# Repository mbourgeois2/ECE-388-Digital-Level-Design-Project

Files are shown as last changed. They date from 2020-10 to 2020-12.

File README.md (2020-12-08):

# ECE-388-Digital-Level-Design-Project
This is my Embedded Systems Design Project for ECE-388, the digital level. The design works as follows. The accelerometer will measure the necessary data. The measured data will then be sent to the PINs of the 328PB and the board tilt angle will be calculated. Firmware written on the microcontroller will determine which LEDs in the LED array to light up based on the data given by the accelerometer. This information will then be output from the PORTs of the 328PB and light up the LEDs accordingly. The LEDs will light up in a similar manner to the movement of a bubble in a bubble level. When the board is completely level, the center LED will turn green. 

Demo video: https://youtu.be/xUTPTQpNgwE (could not fit the MP4 file in the repo, had to upload it to youtube)

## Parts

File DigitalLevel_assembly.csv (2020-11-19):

UUID | Qty | Self Sourced | Value | Device | Package | Parts | Description
R-2019-15 | 8 |  | R | LEDCHIP-LED0805 | CHIP-LED0805 | LED1, LED2, LED3, LED4, LED5, LED6, LED7, LED8 | LED
R-2019-14 | 1 |  | G | LEDCHIPLED_0805 | CHIPLED_0805 | LED9 | LED
R-2019-01 | 5 |  | 0.1uF | C-EUC0805 | C0805 | C1, C2, C3, C4, C7 | CAPACITOR, European symbol
R-2019-44 | 1 |  | 10nF | C-EUC0805 | C0805 | C5 | CAPACITOR, European symbol
R-2019-38 | 1 |  | 1nF | C-EUC0805 | C0805 | C6 | CAPACITOR, European symbol
R-2019-02 | 1 |  | 330R | R-EU_R0805 | R0805 | R1 | RESISTOR, European symbol
R-2019-30 | 3 |  | 4.7kR | R-EU_R0805 | R0805 | R2, R3, R4 | RESISTOR, European symbol
L-2020-48 | 1 |  | ATMEGA328PB-AU | ATMEGA328PB-AU | QFP80P900X900X120-32N | U1 | ATmega Series 20 MHz 32 KB Flash 2 KB SRAM 8-Bit Microcontroller - TQFP-32 Check prices
L-2020-54 | 1 |  | MPU-6050 | MPU-6050 | QFN50P400X400X95-24N | U2 | MPU-6050 Six-Axis (Gyro + Accelerometer) MEMS MotionTrackingâ„¢ Devices
L-2019-90 | 1 |  | RK-2032 | RK-2032 | RK-2032 | BAT1
R-2019-19 | 1 |  | SL2305 | SL2305 | SOT95P240X115-3N | Q1 | P-Channel Power MOSFET
L-2019-76 | 1 |  | SN74HC138PW | SN74HC138PW | SOP65P640X120-16N | U3

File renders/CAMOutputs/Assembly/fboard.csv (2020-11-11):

Qty | Value | Device | Package | Parts | Description | ARROW_PART_NUMBER | ARROW_PRICE-STOCK | AVAILABILITY | DESCRIPTION | DIGI-KEY_PART_NUMBER | HEIGHT | MANUFACTURER_NAME | MANUFACTURER_PART_NUMBER | MF | MOUSER_PART_NUMBER | MOUSER_PRICE-STOCK | MP | PACKAGE | POPULARITY | PRICE | PURCHASE-URL | SPICEPREFIX
8 |  | LEDCHIP-LED0805 | CHIP-LED0805 | LED1, LED2, LED3, LED4, LED5, LED6, LED7, LED8 | LED
1 |  | LEDCHIPLED_0805 | CHIPLED_0805 | LED9 | LED
5 | 0.1uF | C-EUC0805 | C0805 | C1, C2, C3, C4, C7 | CAPACITOR, European symbol |  |  |  |  |  |  |  |  |  |  |  |  |  | 88 |  |  | C
1 | 10nF | C-EUC0805 | C0805 | C5 | CAPACITOR, European symbol |  |  |  |  |  |  |  |  |  |  |  |  |  | 88 |  |  | C
1 | 2nF | C-EUC0805 | C0805 | C6 | CAPACITOR, European symbol |  |  |  |  |  |  |  |  |  |  |  |  |  | 88 |  |  | C
1 | 330R | R-EU_R0805 | R0805 | R1 | RESISTOR, European symbol |  |  |  |  |  |  |  |  |  |  |  |  |  | 86 |  |  | R
3 | 4.7kR | R-EU_R0805 | R0805 | R2, R3, R4 | RESISTOR, European symbol |  |  |  |  |  |  |  |  |  |  |  |  |  | 86 |  |  | R
1 | ATMEGA328PB-AU | ATMEGA328PB-AU | QFP80P900X900X120-32N | U1 | ATmega Series 20 MHz 32 KB Flash 2 KB SRAM 8-Bit Microcontroller - TQFP-32 Check prices |  |  | Good | 8-bit Microcontrollers - MCU ATMEGA328PB 20MHZ IND TEMP |  |  |  |  | Microchip Technology / Atmel |  |  | ATMEGA328PB-AU | None |  | None | https://pricing.snapeda.com/search/part/ATMEGA328PB-AU/?ref=eda
1 | AVRISP-6 | AVRISP-6 | AVRISP | ISP1 | AVR ISP HEADER
3 | FIDUCIAL | FIDUCIAL | FIDUCIAL_1MM | U$4, U$5, U$6 | For use by pick and place machines to calibrate the vision/machine, 1mm
1 | MPU-6050 | MPU-6050 | QFN50P400X400X95-24N | U2 | MPU-6050 Six-Axis (Gyro + Accelerometer) MEMS MotionTracking™ Devices |  |  |  | Accelerometer, Gyroscope, 6 Axis Sensor I²C Output | 1428-1007-1-ND |  |  |  | TDK InvenSense |  |  | MPU-6050 | VFQFN-24 TDK InvenSense |  |  | https://pricing.snapeda.com/search/part/MPU-6050/?ref=eda
1 | RK-2032 | RK-2032 | RK-2032 | BAT1
1 | SL2305 | SL2305 | SOT95P240X115-3N | Q1 | P-Channel Power MOSFET |  |  |  | P-Channel Power MOSFET |  | 1.15mm | Slkor(SLKORMICRO Elec.) | SL2305
1 | SN74HC138PW | SN74HC138PW | SOP65P640X120-16N | U3 |  |  |  | Unavailable | 3-Line To 8-Line Decoders/Demultiplexers 16-TSSOP -40 to 85 |  |  |  |  | Texas Instruments |  |  | SN74HC138PW | TSSOP-16 Texas Instruments |  | None | https://pricing.snapeda.com/search/part/SN74HC138PW/?ref=eda

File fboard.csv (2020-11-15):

Qty | Value | Device | Package | Tolerance | Rating | Parts | Description | LCSC Price 1 | LCSC Price 10 | LCSC Price 100 | LCSC PN | LCSC Link | Digikey Price 1 | Digikey Price 10 | Digikey Price 100 | Digikey PN | Digikey Link | Alt Supplier | Alt Supplier Link
8 | R | LEDCHIP-LED0805 | CHIP-LED0805 |  |  | LED1, LED2, LED3, LED4, LED5, LED6, LED7, LED8 | LED |  |  | $0.014157 | C72044 | https://lcsc.com/product-detail/Light-Emitting-Diodes-LED_0603-Red-LED_C72044.html
1 | G | LEDCHIPLED_0805 | CHIPLED_0805 |  |  | LED9 | LED |  | $0.062285 | $0.046420 | C73546 | https://lcsc.com/product-detail/Light-Emitting-Diodes-LED_0805-Green_C73546.html
5 | 0.1uF | C-EUC0805 | C0805 | 5% | 50V | C1, C2, C3, C4, C7 | CAPACITOR, European symbol |  |  | $0.008557 | C840115 | https://lcsc.com/product-detail/Multilayer-Ceramic-Capacitors-MLCC-SMD-SMT_HUI-JU-NL0805B104J500CPBN_C840115.html
1 | 10nF | C-EUC0805 | C0805 | 5% | 50V | C5 | CAPACITOR, European symbol |  |  | $0.010582 | C24666 | https://lcsc.com/product-detail/Multilayer-Ceramic-Capacitors-MLCC-SMD-SMT_FH-Guangdong-Fenghua-Advanced-Tech-0805B103J500NT_C24666.html
1 | 2nF | C-EUC0805 | C0805 | 5% | 50V | C6 | CAPACITOR, European symbol |  |  | $0.024456 | C520022 | https://lcsc.com/product-detail/Multilayer-Ceramic-Capacitors-MLCC-SMD-SMT_YAGEO-CC0805JRX7R9BB202_C520022.html
1 | 330R | R-EU_R0805 | R0805 | 5% | 0.125W | R1 | RESISTOR, European symbol |  |  | $0.001490 | C25306 | https://lcsc.com/product-detail/Chip-Resistor-Surface-Mount_UNI-ROYAL-Uniroyal-Elec-0805W8J0331T5E_C25306.html
3 | 4.7kR | R-EU_R0805 | R0805 | 5% | 0.125W | R2, R3, R4 | RESISTOR, European symbol |  |  | $0.001350 | C384092 | https://lcsc.com/product-detail/Chip-Resistor-Surface-Mount_Walsin-Tech-Corp-Walsin-Tech-Corp-4-7KR-472-5_C384092.html
1 | ATMEGA328PB-AU | ATMEGA328PB-AU | QFP80P900X900X120-32N |  |  | U1 | ATmega Series 20 MHz 32 KB Flash 2 KB SRAM 8-Bit Microcontroller - TQFP-32 Check prices |  |  |  |  |  | $1.45000 | $1.45000 | $1.20000 | ATMEGA328PB-ANRTR-ND - Tape & Reel (TR) | https://www.digikey.com/en/products/detail/microchip-technology/ATMEGA328PB-ANR/5722705
1 | AVRISP-6 | AVRISP-6 | AVRISP |  |  | ISP1 | AVR ISP HEADER |  |  |  |  |  | $0.16000 | $0.15100 | $0.10480 | S2212EC-03-ND | https://www.digikey.com/en/products/detail/sullins-connector-solutions/PREC003DFAN-RC/2775011
1 | CR2032V | CR2032V | CR2032V |  |  | G1 | LI BATTERY Varta |  |  |  |  |  |  |  |  |  |  | Aliexpress | https://www.aliexpress.com/item/4000204085959.html
1 | MPU-6050 | MPU-6050 | QFN50P400X400X95-24N |  |  | U2 | MPU-6050 Six-Axis (Gyro + Accelerometer) MEMS MotionTrackingâ„¢ Devices | $2.663333 | $1.961667 | $1.703333 | C24112 | https://lcsc.com/product-detail/Attitude-Sensors_TDK-InvenSense_MPU-6050_TDK-InvenSense-MPU-6050_C24112.html
1 | RK-2032 | RK-2032 | RK-2032 |  |  | BAT1 |  |  |  |  |  |  |  |  |  |  |  | Reekart | http://www.reekart.com/products/30-Surface-Mount-Precision-Metal-Stamping-CR2032-Coin-Cell-Battery-Holder-For-MPD-BC-2003-Replacment.html
1 | SL2305 | SL2305 | SOT95P240X115-3N |  |  | Q1 | P-Channel Power MOSFET |  |  | $0.028500 | C426573 | https://lcsc.com/product-detail/MOSFET_Slkor-SLKORMICRO-Elec-SL2305_C426573.html
1 | SN74HC138PW | SN74HC138PW | SOP65P640X120-16N |  |  | U3 |  | $0.148700 | $0.108800 | $0.094200 | C157527 | https://lcsc.com/product-detail/74-Series_Texas-Instruments_SN74HC138PWR_Texas-Instruments-Texas-Instruments-SN74HC138PWR_C157527.html

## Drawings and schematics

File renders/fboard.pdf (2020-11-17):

A

A

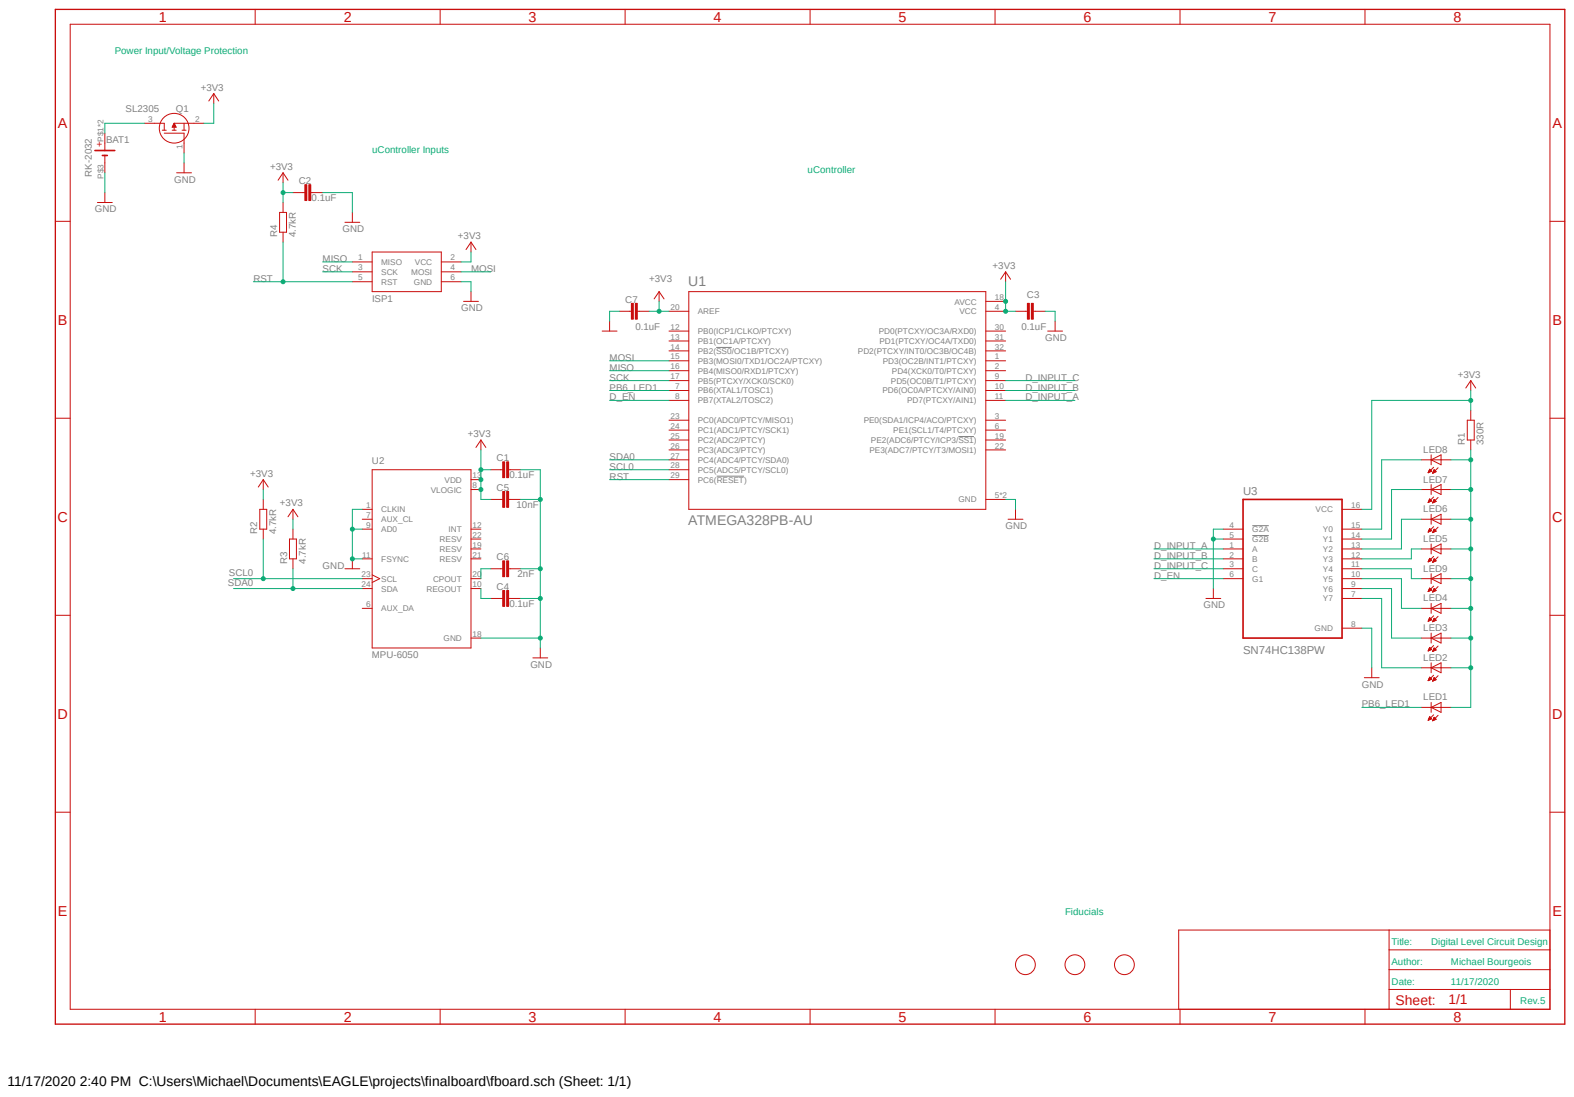
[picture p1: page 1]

Power Input/Voltage Protection

11/17/2020 2:40 PM C:\Users\Michael\Documents\EAGLE\projects\finalboard\fboard.sch (Sheet: 1/1)

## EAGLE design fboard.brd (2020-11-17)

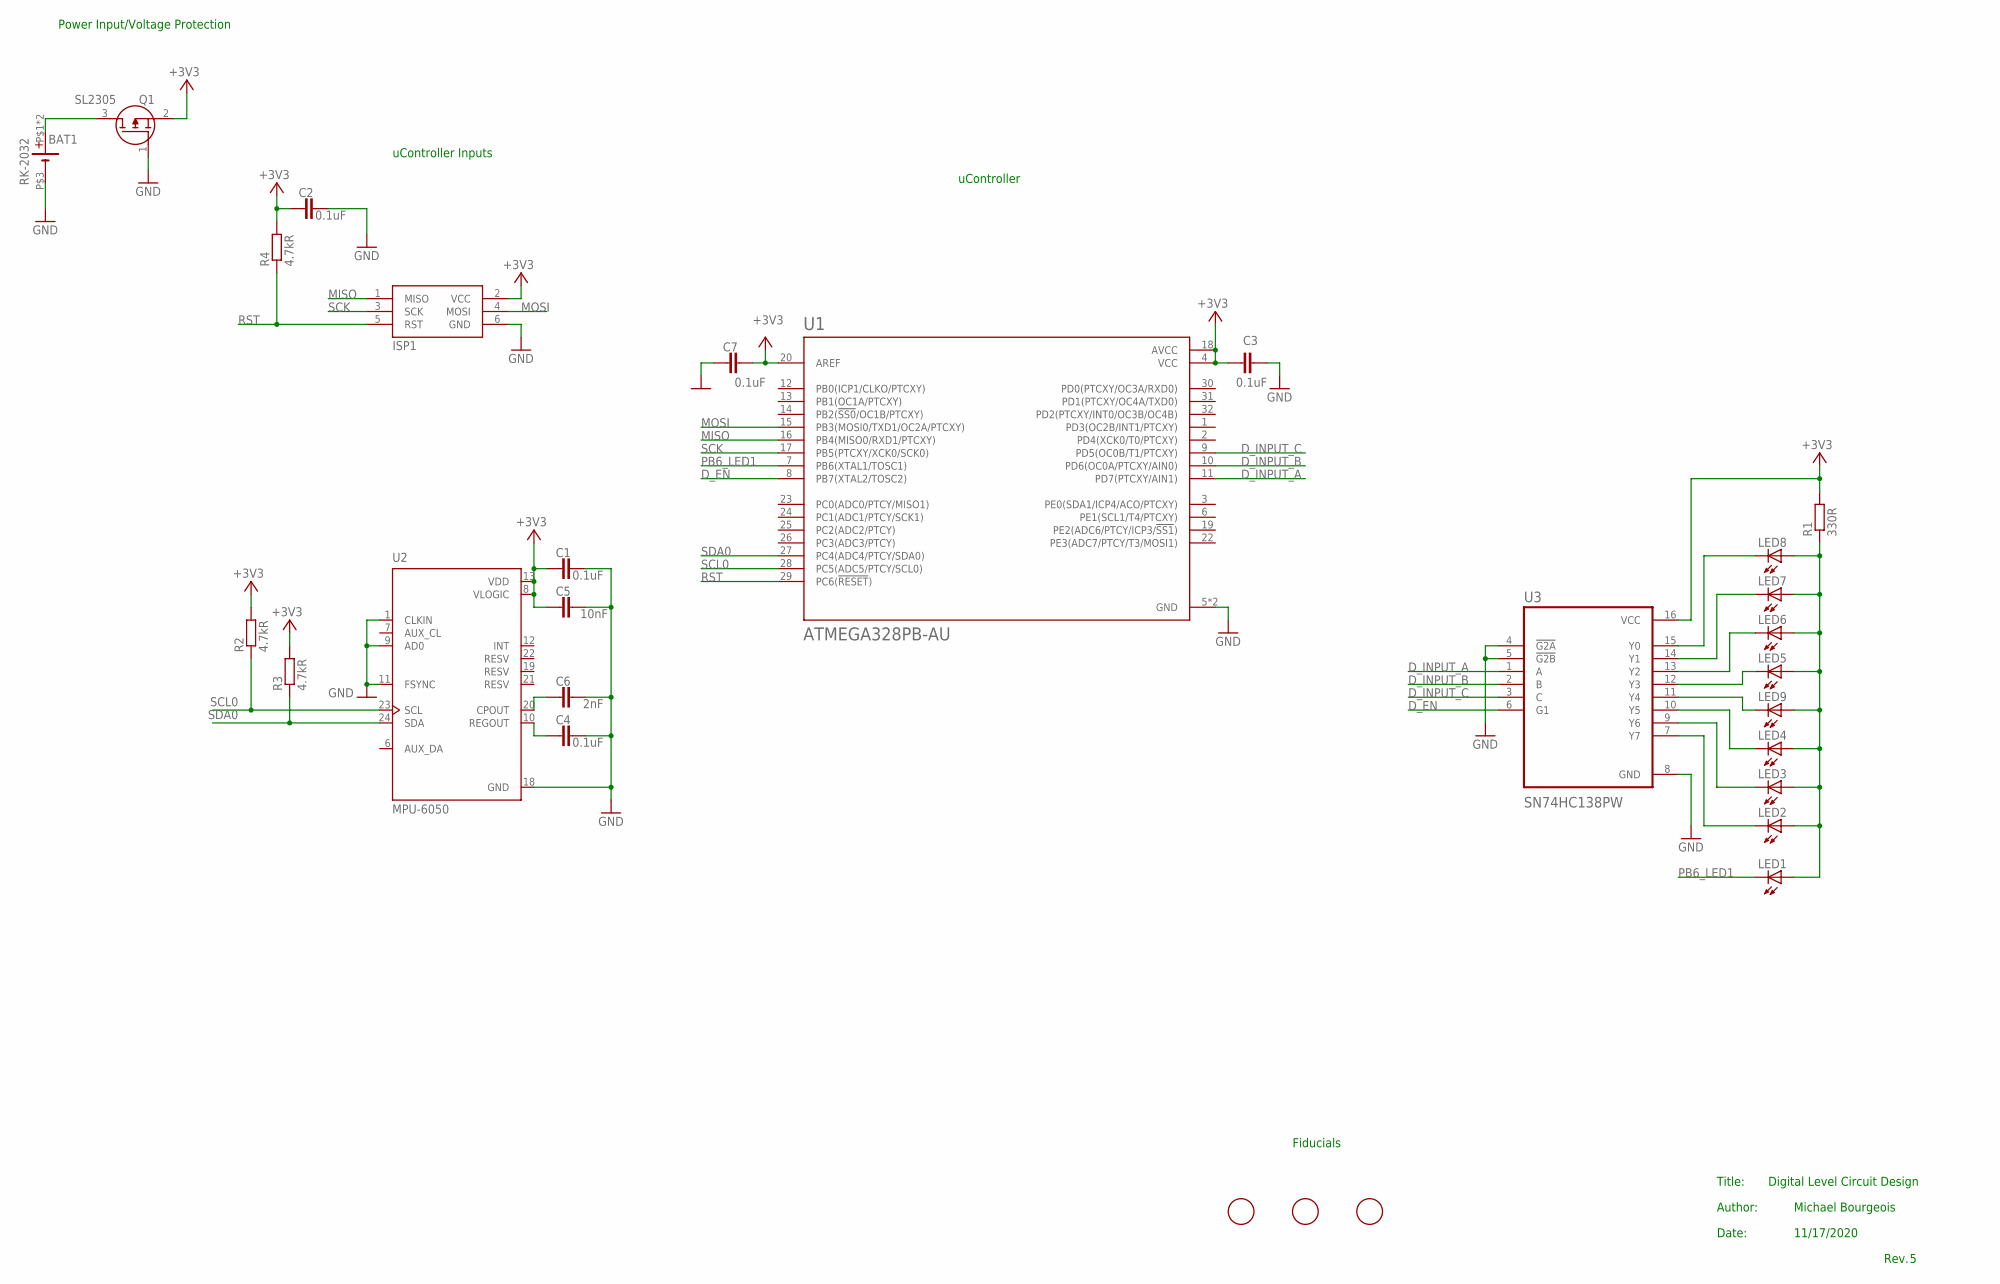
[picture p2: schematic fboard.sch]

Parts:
BAT1: RK-2032
C1, C2, C3, C4, C7: 0.1uF; C0805
C5: 10nF; C0805
C6: 2nF; C0805
ISP1: AVRISP-6; AVRISP
LED1, LED2, LED3, LED4, LED5, LED6, LED7, LED8: LEDCHIP-LED0805; CHIP-LED0805
LED9: LEDCHIPLED_0805; CHIPLED_0805
Q1: SL2305; SOT95P240X115-3N
R1: 330R; R0805
R2, R3, R4: 4.7kR; R0805
U1: ATMEGA328PB-AU; QFP80P900X900X120-32N
U2: MPU-6050; QFN50P400X400X95-24N
U3: SN74HC138PW; SOP65P640X120-16N
U$4, U$5, U$6: FIDUCIAL; FIDUCIAL_1MM

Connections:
+3V3: C1.1, C2.1, C3.1, C5.1, C7.1, ISP1.2 (VCC), Q1.2 (S), R1.2, R2.2, R3.2, R4.2, U1.4 (VCC), U1.18 (AVCC), U1.20 (AREF), U2.8 (VLOGIC), U2.13 (VDD), U3.16 (VCC)
D_EN: U1.8 (PB7(XTAL2/TOSC2)), U3.6 (G1)
D_INPUT_A: U1.11 (PD7(PTCXY/AIN1)), U3.1 (A)
D_INPUT_B: U1.10 (PD6(OC0A/PTCXY/AIN0)), U3.2 (B)
D_INPUT_C: U1.9 (PD5(OC0B/T1/PTCXY)), U3.3 (C)
GND: BAT1.P$3 (-), C1.2, C2.2, C3.2, C4.2, C5.2, C6.2, C7.2, ISP1.6 (GND), Q1.1 (G), U1.5 (GND), U1.21 (GND), U2.1 (CLKIN), U2.9 (AD0), U2.11 (FSYNC), U2.18 (GND), U3.4 (!G2A), U3.5 (!G2B), U3.8 (GND)
LED_LINE: LED1.A, LED2.A, LED3.A, LED4.A, LED5.A, LED6.A, LED7.A, LED8.A, LED9.A, R1.1
MISO: ISP1.1 (MISO), U1.16 (PB4(MISO0/RXD1/PTCXY))
MOSI: ISP1.4 (MOSI), U1.15 (PB3(MOSI0/TXD1/OC2A/PTCXY))
unnamed: C4.1, U2.10 (REGOUT)
unnamed: C6.1, U2.20 (CPOUT)
unnamed: BAT1.P$1 (+), BAT1.P$2 (+), Q1.3 (D)
PB6_LED1: LED1.C, U1.7 (PB6(XTAL1/TOSC1))
RST: ISP1.5 (RST), R4.1, U1.29 (PC6(!RESET!))
SCK: ISP1.3 (SCK), U1.17 (PB5(PTCXY/XCK0/SCK0))
SCL0: R2.1, U1.28 (PC5(ADC5/PTCY/SCL0)), U2.23 (SCL)
SDA0: R3.1, U1.27 (PC4(ADC4/PTCY/SDA0)), U2.24 (SDA)
Y0: LED8.C, U3.15 (Y0)
Y1: LED7.C, U3.14 (Y1)
Y2: LED6.C, U3.13 (Y2)
Y3: LED5.C, U3.12 (Y3)
Y4: LED9.C, U3.11 (Y4)
Y5: LED4.C, U3.10 (Y5)
Y6: LED3.C, U3.9 (Y6)
Y7: LED2.C, U3.7 (Y7)

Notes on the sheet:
11/17/2020
Michael Bourgeois
Title:
Digital Level Circuit Design
Author:
Date:
Rev.
Power Input/Voltage Protection
uController Inputs
uController
Fiducials

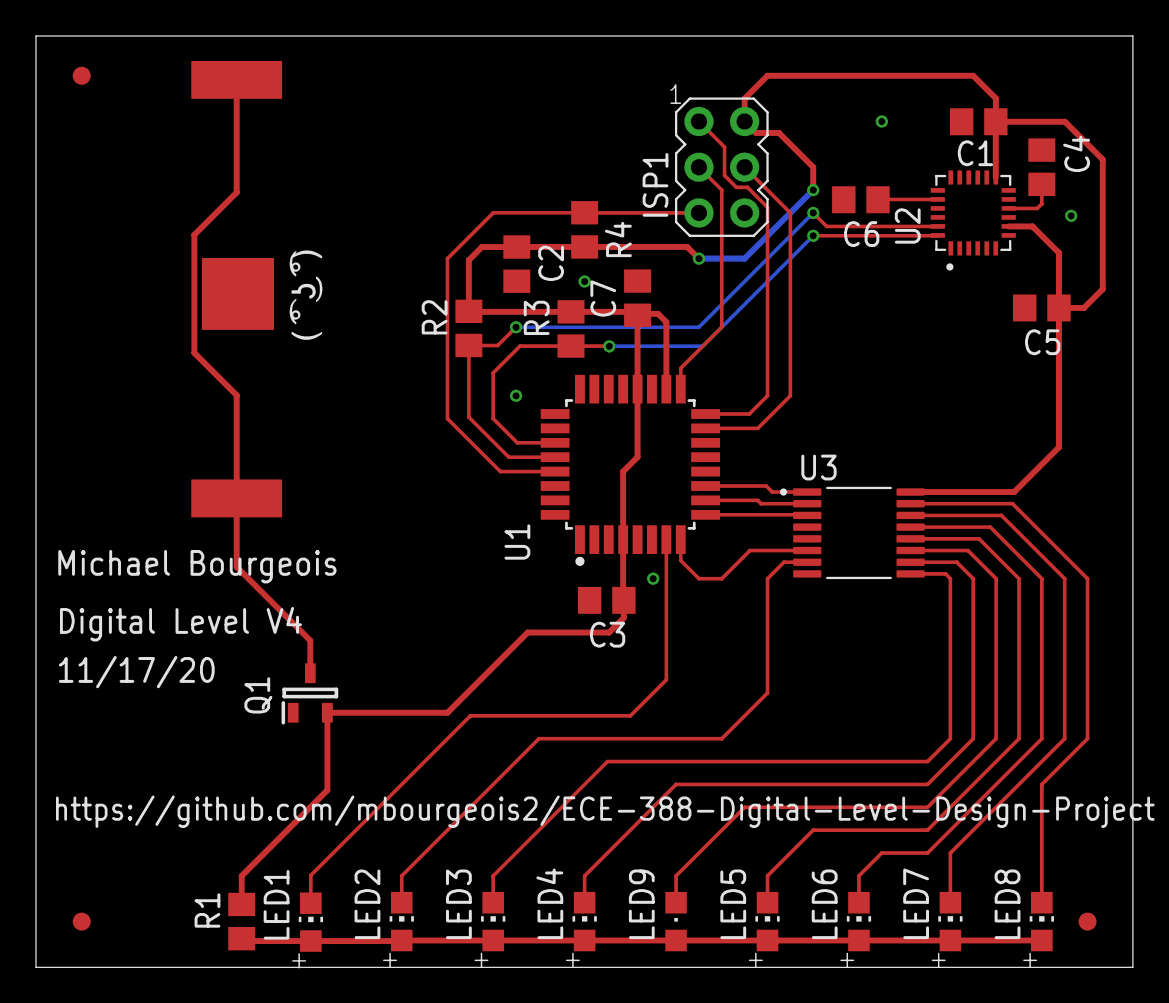
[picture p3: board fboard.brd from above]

Board: 2 copper layers, 60.9 x 51.7 mm, 29 parts (0 on the bottom side), 25 nets.

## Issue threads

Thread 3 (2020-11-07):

Schematic Submission

timChase98, 2020-11-07:
- [x] Render of schematic is rotated 90 degrees
- [x] Schematics should have clear flow from left-right
  - [x] Power input top left
  - [x] Inputs to uController middle left
  - [x] uController in the center
  - [x] uController outputs to right
- [x] Power flags should label the voltage they carry. ie +5V -12V 3.3V
  - [x] Supply flags should always point up
  - [x] GND flags should always point down
  - [x] The battery should be upright
- [x] Your reverse voltage protection would cause a significant voltage drop over the diode.  Take a look at [THIS](https://www.ti.com/lit/an/slva139/slva139.pdf?ts=1602775249932&ref_url=https%253A%252F%252Fwww.google.com%252F) app note from TI
- [x] nonpolarized components should use nonpolarized symbols
  - [x] If C6 is intended to be polarized it's reverse biased
- [x] Why are there resistors on the programming lines?
- [x] Nets should have more meaningful names than PB0

Please address these issues and push your changes. Then create a new release, increment the tag and close this issue. I will review the changes and mark this as complete or reopen the issue with additional feedback.

mbourgeois2, 2020-11-09:
One question, what is the output voltage of the isp programmers? I'm asking because my accelerometer's max voltage is 3.46V and if the programmers output 5V that could be an issue

timChase98, 2020-11-10:
The ISP does not output a voltage

mbourgeois2, 2020-11-10:
ok thank you

timChase98, 2020-11-10:
-[ ] What is the purpose of U3?
-[ ] Clean up the power nets on the top of the MPU-6050

mbourgeois2, 2020-11-10:
U3 is a decoder, I implemented it to try and simplify the wiring on the ports, should I take it back out?

mbourgeois2, 2020-11-11:
@timChase98 hey tim, i'm sorry if you're busy but everyone i've talked to so far has had their schems looked at again, if you haven't gotten to mine yet that's all good, i was just wondering

timChase98, 2020-11-11:
- [ ] Add a pullup resistor to the reset line of the uController
- [ ] Clean up your power nets so everything is pointing in the right direction.
- [ ] VCC on the ISP should connect to the VCC pin of the uController.  You have it connected to the battery

Sorry I had this type out but apparently I never hit send, fix these things and I'll give it a pass

mbourgeois2, 2020-11-11:
@timChase98 Ok I think these are fixed now

mbourgeois2, 2020-11-11:
@timChase98 I don't think you reopened the issue, just letting you know I fixed it, can you please review my changes when you can

timChase98, 2020-11-11:
I'll accept this.  You can move onto payout.  To get a pass all labels should sit on top of the nets they are connected to not next to them.  You did this correct for the net labels on the left side of the uController, fix them everywhere else

mbourgeois2, 2020-11-11:
@timChase98 ok i think i fixed the labels

mbourgeois2, 2020-11-11:
@timChase98 did i pass

timChase98, 2020-11-11:
Looks good. Move onto layout

Closed 2020-11-11.

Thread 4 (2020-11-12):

Board Submission

mbourgeois2, 2020-11-12:
hey tim, I submitted my board, can you look at it when you have time?

timChase98, 2020-11-12:
This actually looks pretty good.  You need to increase the font size for your text, You also need to increase the trace width on your power traces to 12 mil.  Minimum to get manufactured is 6mil or .16mm.  This could fit on a smaller board but if you change the trace width and font size I'll accept this.

mbourgeois2, 2020-11-12:
Thanks for the feedback tim, i made my font bigger, but i thought my power trace width was already 12mil, and the rest of the traces are 8mil

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

mbourgeois2, 2020-11-12:
in addition to this, setting my power trace width any high than 13 results in a clearance error on the mpu-6050, this is demonstrated with the trace width set to 16mil:

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

mbourgeois2, 2020-11-12:
one other thing, would the size of the lenny face next to the battery cause any manufacturing issues? i'd like it to be there but if it comes down to it i don't want sacrifice the manufacturability of my board for a stupid meme

timChase98, 2020-11-12:
Your copper layers look fine. If you wanted to redo your layout after the deadline for more points I would recommend adding a GND plane on the bottom layer.  you still need to increase the stroke size of all of your designators to 6mil or larger.  This also applies to the lenny face.  I believe there is a ULP to do this for you.  Fix the font size and I'll accept this, add the gnd plane and i'll pass it.

mbourgeois2, 2020-11-12:
i did add a ground plane

mbourgeois2, 2020-11-12:
at least i think i do? i made a polygon covering the board, then called it GND, my airwires went away after that

timChase98, 2020-11-12:
Did you update the gerbers on github? The ones I'm looking at doesn't have a plane
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

mbourgeois2, 2020-11-12:
ok i pushed it again, here is a screencap of my board
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
for some reason it only shows up if i run ratsnest

timChase98, 2020-11-12:
You have to run ratsnest for it to actually fill the plane. It also looks like you are using the wrong cam processor.  Use the 388Cam file

mbourgeois2, 2020-11-12:
ok i downloaded a new cam file from the repo and pushed my changes, also adjusted my text

mbourgeois2, 2020-11-12:
also is the correct ULP normalize-text? that't the one i used, a quick google search indicated that stroke size was the ratio times the size of the text

timChase98, 2020-11-12:
The stroke size is the width of a line.  Normalize-text is the correct ULP

mbourgeois2, 2020-11-12:
im trying to generate the gerbers myself and cannot see the ground plane and am not sure why, any ideas?

mbourgeois2, 2020-11-12:
i'm using the ece388 cam file

timChase98, 2020-11-12:
This looks correct now.  I'll pass this

mbourgeois2, 2020-11-12:
you were able to see the ground plane?

timChase98, 2020-11-12:
Yes its there now.  You are good

timChase98, 2020-11-16:
Your board was sent to fab

mbourgeois2, 2020-11-18:
hey tim, so i was doing some more prototyping when i realized that i forgot to ground pins 4&5 on my decoder (seen below)
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

the decoder was a last minute addition and i should have seen this coming if i did more prototyping with it earlier
this means my board will not work straight away, however i was wondering if it would be possible to solder in some rework wires, like this
https://nexlogic.com/wp-content/uploads/2015/10/PCB-Rework2.png
this would make my board (maybe?) function as intended

timChase98, 2020-11-18:
Yes mod wiring is something that you end up doing a lot of in this type of prototyping.  We have all the necessary equipments 211, available any time I'm on campus.

Closed 2020-11-19.

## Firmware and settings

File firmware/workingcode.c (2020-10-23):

/*
 * accelerometertest.c
 *
 * Created: 10/19/2020 10:37:29 PM
 * Author : xxkin
 */ 

#define F_CPU 16000000
#define MPU6050_ADDR 0x68
#define PI 3.141592

#include "twi_master.h"
#include <avr/io.h>
#include <util/delay.h>
#include <math.h>

/************************************************************************/
/*							Initializations                             */
/************************************************************************/

/* MPU6050 register address */
#define ACCEL_XOUT_H	0x3B
#define ACCEL_XOUT_L	0x3C
#define ACCEL_YOUT_H	0x3D
#define ACCEL_YOUT_L	0x3E
#define ACCEL_ZOUT_H	0x3F
#define ACCEL_ZOUT_L	0x40
#define PWR_MGMT_1		0x6B

typedef struct
{
	float x;
	float y;
	float z;
} mpu_data_t;


/************************************************************************/
/*							Prototype functions                         */
/************************************************************************/

void ERROR_CHECK(ret_code_t error_code);
void mpu_init(void);
void mpu_get_accel_raw(mpu_data_t* mpu_data);
void mpu_get_accel(mpu_data_t* mpu_data);


/************************************************************************/
/*							Function definitions                        */
/************************************************************************/

void ERROR_CHECK(ret_code_t error_code)
{
	if (error_code != SUCCESS)
	{
		while (1); // loop indefinitely
	}
}


void mpu_init(void)
{
	ret_code_t error_code;
	//puts("Write 0 to PWR_MGMT_1 reg to wakeup MPU.");
	uint8_t data[2] = {PWR_MGMT_1, 0};
	error_code = tw_master_transmit(MPU6050_ADDR, data, sizeof(data), false);
	//ERROR_CHECK(error_code);
}


void mpu_get_accel_raw(mpu_data_t* mpu_data)
{
	ret_code_t error_code;
	/* 2 registers for each of accel x, y and z data */
	uint8_t data[6];
	
	data[0] = ACCEL_XOUT_H;
	error_code = tw_master_transmit(MPU6050_ADDR, data, 1, true);
	//ERROR_CHECK(error_code);
	
	error_code = tw_master_receive(MPU6050_ADDR, data, sizeof(data));
	//ERROR_CHECK(error_code);
	
	/* Default accel config +/- 2g */
	mpu_data->x = (int16_t)(data[0] << 8 | data[1]) / 16384.0;
	mpu_data->y = (int16_t)(data[2] << 8 | data[3]) / 16384.0;
	mpu_data->z = (int16_t)(data[4] << 8 | data[5]) / 16384.0;
}


void mpu_get_accel(mpu_data_t* mpu_data)
{
	mpu_get_accel_raw(mpu_data);
	mpu_data->x = mpu_data->x * 9.81;
	mpu_data->y = mpu_data->y * 9.81;
	mpu_data->z = mpu_data->z * 9.81;
}


/************************************************************************/
/*							Main application                            */
/************************************************************************/

int main(void)
{
	DDRD = 0xFF;
	DDRB = 0x01;
	/* Initialize project configuration */
	tw_init(TW_FREQ_400K, true); // set I2C Frequency, enable internal pull-up
	mpu_init();
	mpu_data_t accel;
	float roll=0,pitch=0;
	int i = 0;
	while (1)
	{
		//puts("Read accelerometer data.");
		mpu_get_accel(&accel);
		roll = atan(-accel.y / accel.z)*180/PI;
		pitch = atan(accel.x / sqrt(pow(accel.y,2) + pow(accel.z,2)))*180/PI;
		i = 4.5 + (roll/20);
		if (i < 8)
		{
			PORTB = 0x00;
			PORTD = (1<<(i));
		}
		else if (i == 8)
		{
			PORTD = 0x00;
			PORTB = 0x01;
		}
		else
		{
			PORTD = 0x00;
			PORTB = 0x00;
		}
		_delay_ms(100);
	}
}

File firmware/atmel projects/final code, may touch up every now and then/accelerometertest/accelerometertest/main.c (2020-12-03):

/*
 * accelerometertest
 *
 * Created: 10/19/2020 10:37:29 PM
 * Author : mbourgeois2
  heavily based off of https://github.com/YifanJiangPolyU/MPU6050
 */ 

//#define F_CPU 1000000
#define MPU6050_ADDR 0x68
#define PI 3.141592

#include "twi_master.h"
#include <avr/io.h>
#include <math.h>

/************************************************************************/
/*							Initializations                             */
/************************************************************************/

/* MPU6050 register address */
#define ACCEL_XOUT_H	0x3B
#define ACCEL_XOUT_L	0x3C
#define ACCEL_YOUT_H	0x3D
#define ACCEL_YOUT_L	0x3E
#define ACCEL_ZOUT_H	0x3F
#define ACCEL_ZOUT_L	0x40
#define PWR_MGMT_1		0x6B

typedef struct
{
	float x;
	float y;
	float z;
} mpu_data_t;


/************************************************************************/
/*							Prototype functions                         */
/************************************************************************/

void ERROR_CHECK(ret_code_t error_code);
void mpu_init(void);
void mpu_get_accel_raw(mpu_data_t* mpu_data);
void mpu_get_accel(mpu_data_t* mpu_data);
uint8_t dindex(int q);
void dispdig(int q);

/************************************************************************/
/*							Function definitions                        */
/************************************************************************/

void ERROR_CHECK(ret_code_t error_code)
{
	if (error_code != SUCCESS)
	{
		while (1); // loop indefinitely
	}
}

void mpu_init(void)
{
	ret_code_t 
	error_code;
	//puts("Write 0 to PWR_MGMT_1 reg to wakeup MPU.");
	uint8_t data[2] = {PWR_MGMT_1, 0};
	error_code = tw_master_transmit(MPU6050_ADDR, data, sizeof(data), false);
	//ERROR_CHECK(error_code);
}


void mpu_get_accel_raw(mpu_data_t* mpu_data)
{
	ret_code_t error_code;
	/* 2 registers for each of accel x, y and z data */
	uint8_t data[6];
	
	data[0] = ACCEL_XOUT_H;
	error_code = tw_master_transmit(MPU6050_ADDR, data, 1, true);
	//ERROR_CHECK(error_code);
	
	error_code = tw_master_receive(MPU6050_ADDR, data, sizeof(data));
	//ERROR_CHECK(error_code);
	
	/* Default accel config +/- 2g */
	mpu_data->x = (int16_t)(data[0] << 8 | data[1]) / 16384.0;
	mpu_data->y = (int16_t)(data[2] << 8 | data[3]) / 16384.0;
	mpu_data->z = (int16_t)(data[4] << 8 | data[5]) / 16384.0;
}


void mpu_get_accel(mpu_data_t* mpu_data)
{
	mpu_get_accel_raw(mpu_data);
	mpu_data->x = mpu_data->x * 9.81;
	mpu_data->y = mpu_data->y * 9.81;
	mpu_data->z = mpu_data->z * 9.81;
}

uint8_t dindex(int q)
{
	uint8_t a=0,b=0,c=0;
	a = (q&1)<<2;
	b = q&2;
	c = (q&4)>>2;
	return (a+b+c);
}

void dispdig(int q)
{
	PORTD = 0x00;
	PORTB = 0b11000000;
	int k = 0, yes = 16384;
	while(yes > 0)
	{
		PORTD = (dindex(k) << 5);
		k++;
		if (k > (q-1))
			k=0;
		yes--;
	}
	PORTB = 0x00;
	PORTD = 0x00;
}

/************************************************************************/
/*							Main application                            */
/************************************************************************/

int main(void)
{
	DDRD = 0xFF;
	DDRB = 0b11000000;
	/* Initialize project configuration */
	tw_init(TW_FREQ_400K, true); // set I2C Frequency, enable internal pull-up
	mpu_init();
	mpu_data_t accel;
	float roll = 0, range = 0, x = 0, y = 0, z = 0, alpha = 0.9;
	uint8_t i = 0, j = 0, mode = 1, modeselect = mode*(mode - 2) + 3;
	x = accel.x;
	y = accel.y;
	z = accel.z;
	while (1)
	{
		//puts("Read accelerometer data.");
		mpu_get_accel(&accel);
		//actual config
		
		//lowpass filter to smooth accelerometer data
		x = accel.x + alpha*(x - accel.x);
		y = accel.y + alpha*(y - accel.y);
		z = accel.z + alpha*(z - accel.z);
		
		//sensitivity mode check
		if ((sqrt(pow(accel.x,2) + pow(accel.y,2) + pow(accel.z,2)) >= 32)) //min 32?
		{
			mode++;
			if (mode > 3)
				mode = 1;
			dispdig(mode);
			modeselect = mode*(mode - 2) + 3;
		}
				
		//angle and LED calculations
		range = 90/modeselect;
		roll = ((atan(-y / z)*180/PI)+90)*(z/fabs(z));
		if ((90 - range <= roll) && (90 + range > roll))
		{
			i = ((roll - range*(modeselect - 1))*modeselect/20);		//default roll/20	//obsolete (roll - range*(modeselect - 1))*modeselect/20;
			i=8-i;
			j = dindex(i);
			PORTB = (((~(i) & 0x08))<<4) | (((~(i) & 0x08))<<3);	//enable decoder | enable led8
			PORTD = (((j) & 0x0F)<<5);
		}
		else
		{
			PORTD = 0x00;
			PORTB = (1<<6);
		}
		
		//test config
		//roll = ((atan(-accel.y / accel.z)*180/PI)+90);
		//i = roll/20;
		//pitch = atan(accel.x / sqrt(pow(accel.y,2) + pow(accel.z,2)))*180/PI;
		//i = 4.5 + (roll/20);
		//i = 4 + (roll/22.5);
		
		
		//test code that works
		/*
		if (i < 8)
		{
			PORTB = 0x00;
			PORTD = (1<<(i));
		}
		if (i == 8)
		{
			PORTD = 0x00;
			PORTB = 0x01;
		}
		if (i == 9)
		{
			PORTD = 0x00;
			PORTB = 0x00;
		}
		_delay_ms(100);
		*/
		
		
		//prototype v2 (implemented decoder)
		/*
		if (i == 9)
		{
			PORTD = 0x00;
			PORTB = 0x00;
		}
		else
		{
			PORTD = (((i) & 0x0F)<<5);
			PORTB = (((~(i) & 0x08))<<4) | (((~(i) & 0x08))<<3);
		}
		*/
		/*
		//prototype v3 (prototype demonstration)
		if (i == 9)
		{
			PORTD = 0x00;
			PORTB = 0x01;
		}
		else
		{
			PORTD = (((i) & 0x0F)<<5);
			PORTB = (((~(i) & 0x08))>>2) | (((~(i) & 0x08))>>3);
		}
		*/
		//final code?
		//PORTB = 0b10000000;
		//_delay_ms(50);
	}
}

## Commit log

2020-11-06 fixed bom
    [fboard.csv]
2020-11-06 fixed bom again
    [fboard.csv]
2020-11-09 fixed schematic
    [PnP_fboard_front.csv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]
2020-11-09 fixed more stuff
    [PnP_fboard_front.csv, fboard.brd, fboard.csv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]
2020-11-09 edited schematic again
2020-11-09 removed switch
2020-11-09 removed switch from bom
    [fboard.csv]
2020-11-09 removed diode and fixed pmos
2020-11-11 updated stuff
    [PnP_fboard_front.csv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]
2020-11-11 oops deleted renders folder
    [PnP_fboard_front.csv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]
2020-11-11 moar schematic
2020-11-11 board stuff
    [PnP_fboard_front.csv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]
2020-11-11 moved a capacitor to reduce noise for pullups
    [PnP_fboard_front.csv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]
2020-11-11 more stuff
    [gerber_job.gbrjob]
2020-11-11 thicc power traces
    [PnP_fboard_front.csv, fboard.brd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]
2020-11-11 tried to organize silkscreen, also power trace is 13mil
    [fboard.brd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]
2020-11-12 added easter egg
    [PnP_fboard_front.csv, fboard.brd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]
2020-11-12 bigger font and power traces are 12mil
    [PnP_fboard_front.csv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]
2020-11-12 ground plane?
    [PnP_fboard_front.csv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]
2020-11-12 text size and new cam file
    [PnP_fboard_front.csv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]
2020-11-12 fixed airwire
    [fboard.brd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]
2020-11-12 redid ground plane
    [PnP_fboard_front.csv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]
2020-11-12 i know tim checked me off but i noticed q1 was still on the pad
    [fboard.brd, fboard.csv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]
2020-11-12 last minute fixes
    [fboard.brd, fboard.csv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]
2020-11-15 updated bom
    [fboard.csv]
2020-11-17 grounded ~g2a and ~g2b
    [fboard.brd, fboard.sch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]
2020-11-17 forgot to increment board version
    [fboard.brd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]
2020-11-19 added prototype firmware
2020-11-19 added assembly bom
    [DigitalLevel_assembly.csv]
